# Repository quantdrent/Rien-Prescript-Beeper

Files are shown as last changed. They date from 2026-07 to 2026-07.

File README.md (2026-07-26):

<p align="center"><strong>Rien Index Beeper Device.</strong></p>

<p align="center">
  Rien Prescript Beeper Thumbnail
    <br/>
   
</p>

<p align="center">
The main goal for this project was to make a budget Index Oracle's proxy / Rien device. This runs on Web BLE (so it connects directly to your browser without needing weird setups). This project is under the MIT license so you are free to do anything with it (this includes selling this stuff) but don't try to gatekeep lol. Also, if you decide to make this, feel free to show me! I wanna see it. Hit up @quantdrent on TikTok, Twitter, and Discord.
<br/><br/>
If you want to use the beeper, <a href="https://quantdrent.github.io/Rien-Prescript-Beeper">visit the Web App</a>. or open the html from source code<br/>
<strong>Note: You need to use a browser that supports Web BLE</strong> (Chrome, Edge, Opera, etc).
</p>

## Features
- **Web BLE Integration:** Control the device, sync settings, and beam prescripts right from Chrome/Edge/Opera (no app installs needed).
- **Custom Prescripts:** Write, import, and export your own custom prescripts via the web interface.
- **Stats Tracking:** Physically tap the capacitive touch buttons to **Pass** or **Fail** a prescript, and the device will keep track of your stats.
- **Deep Sleep Mode:** (Recommended Build only) Actually decent battery life for standby.

## Hardware Versions & Required Materials

> There are three different hardware setups in this project:
> * **The nRF52840 (Recommended Build).** It has a TFT color screen, custom fonts, and deep sleep mode. This is the recommended version you see in the GIF.
> * **The ESP32-C3 (Alternative Build).** This uses the exact same TFT color screen as the recommended build, but runs on a much cheaper ESP32-C3 SuperMini. It lacks deep sleep but is a great budget alternative.
> * **The ESP32-C3 (Legacy OLED Build).** An older, archived build that uses a basic blue 1.3" OLED screen. You can find its firmware in `firmware/ESP32/PrescriptBeeper_Legacy_OLED`.
> 
> **DO NOT mix the parts (if you dont know what youre doing).** The firmwares and 3D printed cases are **NOT** interchangeable between the different screens and boards. Make sure you pick the right firmware and 3D model for your parts.

<details>
<summary><strong>Recommended Build (nRF52840)</strong></summary>

This is the recommended version with a tft color screen, custom proportional fonts, and deep sleep support.

> **Note:** Don't forget to solder the boost pads on the SuperMini board if your battery is more than 500mAh.
>
> The TFT `BL` (Backlight) pin MUST be wired to `GND` for the screen to turn on

**Required Parts:**
- SuperMini nRF52840 [[AliExpress](https://www.aliexpress.com/item/1005006019812115.html)]
- 2.25 Inch TFT LCD Module 76x284 ST7789 [[AliExpress](https://www.aliexpress.com/item/1005011855033572.html)]
- 2x Touch capacitive switches TTP-223 [[AliExpress](https://www.aliexpress.com/item/32964219843.html)]
- Any small buttons that can fit inside the case
- Wires (AWG 24 recommended)
- 3.7V Lipo Battery (just make sure it fits in the case)

**Required Arduino Libraries:**
- `Adafruit GFX Library`
- `Adafruit LittleFS`
- `Adafruit ST7735 and ST7789 Library`
**3D Printing (Case):**
- **For the Recommended Build (nRF52840 Supermini):** Use `models/Case.3mf` or `models/Case.stl`
- *(Tinkercad remix link available in `models/tinkercadlink.txt`. I recommend using `.3mf` files. Best results were on a BambuLab A1 with 0.4 nozzle and SUNLU PLA+ 2.0)*

**Wiring Diagram:**
<p align="center">
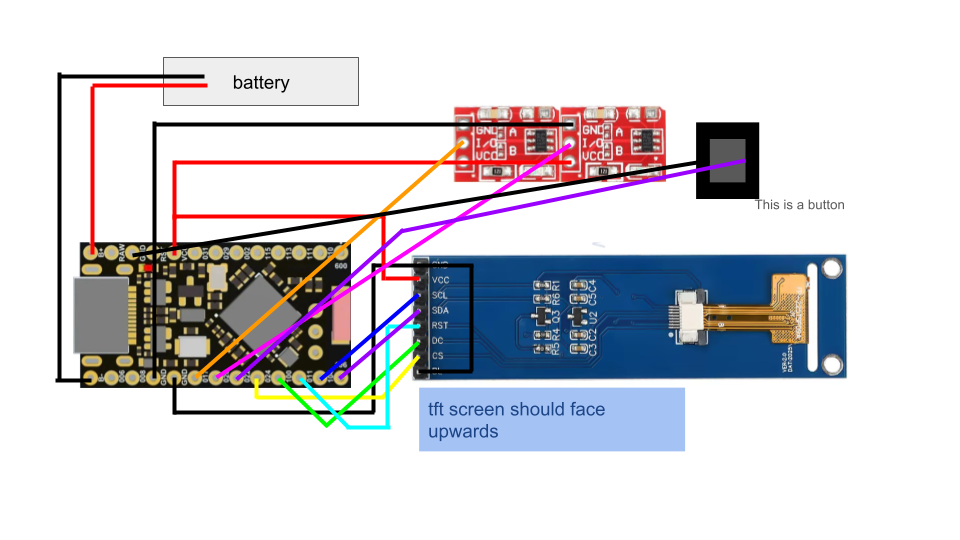
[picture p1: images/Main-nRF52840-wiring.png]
Main nRF52840 Wiring
  
</p>

#### Board Setup (Arduino IDE)
1. Open Arduino v2.x IDE.
2. Go to **File > Preferences**.
3. Click the icon on the right-hand side of “Additional boards manager URLs”.
4. Add the following URL lines into the text box and click OK:
   * **Temporary fix (use this for now):**
     `https://files.seeedstudio.com/arduino/package_seeeduino_boards_index.json`
     `https://raw.githubusercontent.com/pdcook/nRFMicro-Arduino-Core/3dab6477754d9b28053fe36b06c718cde6e93d3f/package_nRFMicro_index.json`
   * *(Note: The official URL without the hash currently has issues, use the temporary fix).*
5. Go to the Boards Manager (**Tools > Board > Boards Manager**).
6. Search for “nrfmicro”.
7. Find the “nRFMicro-like-Boards” by pdcook, and click “Install”.
8. Go to **Tools > Board > nRFMicro-like-Boards > “SuperMini nRF52840”** (Restart Arduino IDE if it is not listed).
9. Plug in your board to a USB port, click the board selector, and choose the relevant port.

#### Updating the Bootloader
The SuperMini nRF52840 boards have nice!nano v2 compatibility, meaning the Adafruit nRF52 Bootloader can be easily updated.

1. Open your file explorer and look for a USB drive related to your board, often called “NICENANO” (if it isn’t visible, quickly ground the RST pin twice to enter bootloader mode).
2. Inside, `INFO_UF2.TXT` is a small text file that states the current bootloader version.
3. You can see the latest bootloader version on the [bootloader github releases page](https://github.com/adafruit/Adafruit_nRF52_Bootloader/releases).
4. **To update via Arduino IDE:**
   * Go to **Tools > Programmer**, and select **“Bootloader DFU for Bluefruit nRF52”**.
   * Go to **Tools > Burn Bootloader**.
   * **Be patient whilst the bootloader is updated. It is critical not to disconnect mid-update, as you could brick the board.**
5. Once updated, recheck the `INFO_UF2.TXT` file to ensure the version has updated (e.g., from 0.6.0 to 0.9.2).
</details>

<details>
<summary><strong>Alternative Build (ESP32-C3 TFT)</strong></summary>

This version is kept here because the ESP32 parts are generally much cheaper and easier to source than the nRF52840, while still allowing you to use the premium TFT color screen.

> **If you are using an ESP32C3** check out [this guide](https://randomnerdtutorials.com/getting-started-esp32-c3-super-mini/) to set up your board in Arduino IDE.
>
> The TFT `BL` (Backlight) pin MUST be wired to `GND` for the screen to turn on

instruction for this version have not been completed. this was a port made by someone else

**Required Parts:**
- ESP32C3 SuperMini (any ESP32 SuperMini should work)
- 2.25 Inch TFT LCD Module 76x284 ST7789 [[AliExpress](https://www.aliexpress.com/item/1005011855033572.html)]
- 2x Touch capacitive switches TTP-223 [[AliExpress](https://www.aliexpress.com/item/32964219843.html)]
- Any small slide switch that fits inside the case [[AliExpress](https://www.aliexpress.com/item/1005011902173007.html)]
- Wires (AWG 26 recommended)

(optional)
- Any small slide switch that fits inside the case [[AliExpress](https://www.aliexpress.com/item/1005011902173007.html)]
- TP4056 Type-C Charger [[AliExpress](https://www.aliexpress.com/item/1005006043031985.html)]
- 3.7V Lipo Battery (just make sure it fits in the case)

**Required Arduino Libraries:**
- `Adafruit GFX Library`
- `Adafruit LittleFS`
- `Adafruit ST7735 and ST7789 Library`

**3D Printing (Case):**
- **For the Alternative Build (ESP32-C3 Supermini):** Use `models/Case.3mf` or `models/Case.stl`
- Best results were on a BambuLab A1 with 0.4 nozzle and SUNLU PLA+ 2.0)*

**Wiring Table:**
| ESP32-C3 SuperMini Pin | Component / Peripheral Pin |
| :--- | :--- |
| **`GPIO 0`** | TFT `MOSI` (or `SDA`) |
| **`GPIO 1`** | TFT `SCLK` (or `SCL`) |
| **`GPIO 2`** | TFT `CS` |
| **`GPIO 3`** | TFT `DC` (or `RS`) |
| **`GPIO 4`** | TFT `RST` |
| **`GPIO 5`** | Pass Button (TTP-223) `I/O` |
| **`GPIO 6`** | Fail Button (TTP-223) `I/O` |
| **`3.3V`** | TFT `VCC`, Buttons `VCC` |
| **`GND`** | TFT `GND`, TFT `BL`, Buttons `GND` |

*(Note: For the charging module, solder it the exact same way as shown in the Legacy version's wiring diagram. The slide switch does not connect to a GPIO pin; wire it inline with the OUT+ of the charging module to act as a physical power switch).*
</details>

<details>
<summary><strong>Legacy Build (ESP32-C3 OLED)</strong></summary>

This is the archived legacy version using a monochrome OLED. You can find its firmware in `firmware/ESP32/PrescriptBeeper_Legacy_OLED`.

**Required Parts:**
- ESP32C3 Super Mini
- 1.3 Inch OLED Screen SH1106 [[AliExpress](https://www.aliexpress.com/item/1005006862867338.html)]
- 2x Touch capacitive switches TTP-223
- Wires (AWG 26 recommended)

(optional)
- Any small slide switch that fits inside the case [[AliExpress](https://www.aliexpress.com/item/1005011902173007.html)]
- TP4056 Type-C Charger [[AliExpress](https://www.aliexpress.com/item/1005006043031985.html)]
- 3.7V Lipo Battery (just make sure it fits in the case)

**Required Arduino Libraries:**
- `Adafruit GFX Library`
- `Adafruit SH110X`

**3D Printing (Case):**
- **For the Legacy Build (ESP32-C3 Supemini):** Use `models/Legacy-Case.3mf` or `models/Legacy-Case.stl`
- I recommend using `.3mf` files. Best results were on a BambuLab A1 with 0.4 nozzle and SUNLU PLA+ 2.0)*

**Wiring Diagram:**
<p align="center">
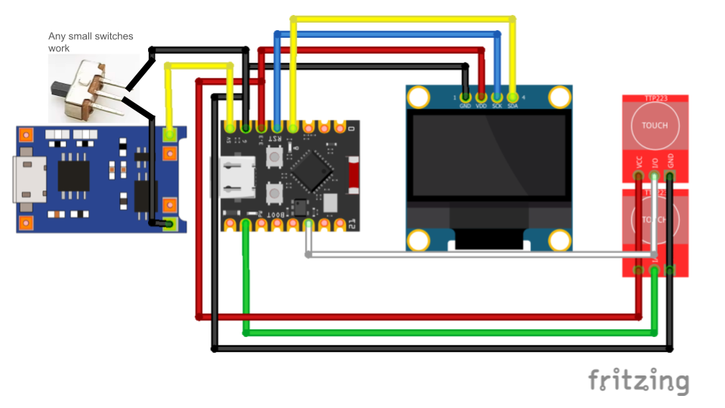
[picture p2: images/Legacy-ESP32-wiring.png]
Legacy ESP32 Wiring
  
</p>

*(Note: The slide switch does not connect to a GPIO pin; wire it inline with the OUT+ of the charging module to act as a physical power switch, as shown in the diagram).*
</details>

## Quickstart

### Instructions

> **Note:** some knowledge of soldering is needed. Don't forget you need a soldering iron, solder, and maybe some flux to connect them all

1. Click the `<> Code` button and download the ZIP, or check releases.
2. Open the `firmware/` folder, select your microcontroller's folder, and open the `.ino` file in the Arduino IDE.
3. Solder everything together based on the pins defined in your firmware's `config.h` file or refer to the hardware sections above for wiring diagrams. 
4. Upload the sketch to your board.
5. Open the [Web App](https://quantdrent.github.io/Rien-Prescript-Beeper) in your browser (or open the local `index.html` file to use offline).
6. Click **Pair Device** and connect to your beeper and your device should work now.
7. Click **Prescripts** at the top middle to add or remove your saved prescripts. You can also export/import them (export first to see the formatting template).
8. Click the giant button on the web app to send a random prescript, or physically tap the capacitive buttons on your device to pull one up.
9. You can factory reset the device by pressing the red button at the bottom right of the settings menu.

## Credits
This project and the Web BLE page were inspired by and forked from Kritzkingvoid's Prescript web project.
https://kritzkingvoid.github.io/Prescripts/

Sounds were taken from Limbus Company / Project Moon.

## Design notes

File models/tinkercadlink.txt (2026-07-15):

this is for the normal case, legacy version is long gone lol

https://www.tinkercad.com/things/3YSkI8xj62Y-rien-index-beeper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

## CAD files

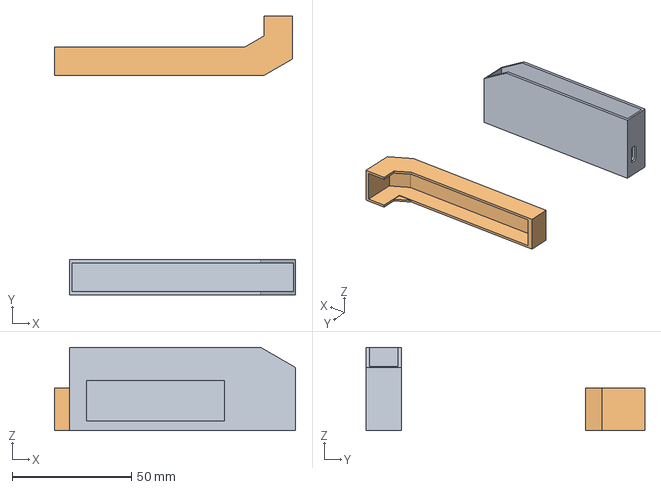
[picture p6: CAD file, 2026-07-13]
models/Case.3mf
101.4 x 117.1 x 35.0 mm
Grand Waasa-Trug(2).stl_5
Grand Waasa-Trug(2).stl_2

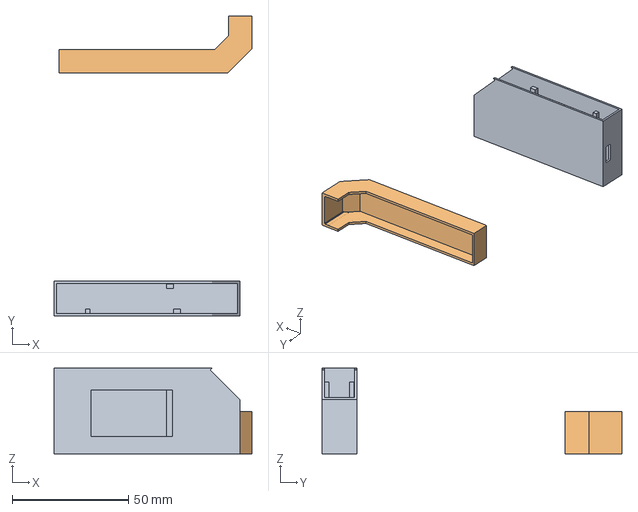
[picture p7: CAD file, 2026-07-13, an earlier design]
models/Legacy-Case.3mf
85.2 x 129.2 x 37.0 mm
larp.stl_2
larp.stl_1

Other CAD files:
models/Case.stl
models/Legacy-Case.stl

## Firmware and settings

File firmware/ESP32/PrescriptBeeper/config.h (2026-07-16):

#ifndef CONFIG_H
#define CONFIG_H

#include <Arduino.h>

extern int textScale;
extern int scrambleDurationFrames;
extern int scrambleDelayMs;
extern int revealDelayMs;
extern int timerPosition;
extern float timerScale;
extern bool bleRequirePin;
extern bool useProportionalFont;

#define TFT_WIDTH 284
#define TFT_HEIGHT 76

#define TFT_MOSI  0
#define TFT_SCLK  1
#define TFT_CS    2
#define TFT_DC    3
#define TFT_RST   4

#define BUTTON_PASS_PIN  5
#define BUTTON_FAIL_PIN  6

#define DEBOUNCE_DELAY  50

#define BLE_CHUNK_SIZE      20
#define BLE_CHUNK_DELAY_MS  10

#define CUSTOMS_FILE    "/customs.txt"
#define STATS_FILE      "/stats.txt"
#define SETTINGS_FILE   "/settings.txt"

#define DEFAULT_TEXT_SCALE          1
#define DEFAULT_SCRAMBLE_FRAMES     20
#define DEFAULT_SCRAMBLE_DELAY      20
#define DEFAULT_REVEAL_DELAY        20

#define COLOR_BG    0x0000
#define DEFAULT_TEXT_COLOR 0xBF5F
extern uint16_t textColor;
extern bool timerFormatLong;

#endif

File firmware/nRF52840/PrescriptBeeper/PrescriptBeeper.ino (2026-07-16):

#include <nrf_wdt.h>
#include "config.h"
#include "display.h"
#include "storage.h"
#include "ble_handler.h"

unsigned long lastDebounceTimePass = 0;
unsigned long lastDebounceTimeFail = 0;
unsigned long lastDebounceTimePower = 0;
int lastPassState = HIGH;
int lastFailState = HIGH;
int lastPowerState = HIGH;
bool passHandled = false;
bool failHandled = false;
unsigned long powerPressedTime = 0;
bool bleRequirePin = false;

void enterSleep() {
  Serial.println("CLEARING DISPLAY");
  isDisplaying = false;
  currentDisplayText = "";
  displayIdle();
  tft.fillScreen(COLOR_BG);

  Serial.println("STOPPING BLE");
  Bluefruit.Advertising.stop();
  if (Bluefruit.connected()) {
    Bluefruit.disconnect(Bluefruit.connHandle());
  }
  delay(200);

  Serial.println("KILLING VCC");
  digitalWrite(EXT_VCC, LOW);
  delay(100);

  Serial.println("WAITING FOR BUTTON RELEASE");
  while(digitalRead(BUTTON_POWER_PIN) == LOW) {
    delay(10);
  }
  delay(300);

  Serial.println("SLEEP STEP 5: CONFIGURING WAKEUP PIN");
  nrf_gpio_cfg_sense_input(g_ADigitalPinMap[BUTTON_POWER_PIN], NRF_GPIO_PIN_PULLUP, NRF_GPIO_PIN_SENSE_LOW);

  Serial.println("ENTERING SYSTEM OFF");
  Serial.flush();
  delay(100);

  sd_power_system_off();
  while(1) {
    __WFE();
  }
}

unsigned long displayStartTime = 0;
unsigned long displayDurationMs = 0;
bool isDisplaying = false;
bool isInfinite = false;
String currentDisplayText = "";
bool pendingDisplayUpdate = false;

void setup() {
  Serial.begin(115200);

  pinMode(BUTTON_PASS_PIN, INPUT_PULLUP);
  pinMode(BUTTON_FAIL_PIN, INPUT_PULLUP);
  pinMode(BUTTON_POWER_PIN, INPUT_PULLUP);

  pinMode(EXT_VCC, OUTPUT);
  digitalWrite(EXT_VCC, HIGH);

  InternalFS.begin();
  readSettings();

  displayInit();
  displayIdle();

  bleInit();
  startAdv();

  NRF_WDT->CONFIG = 0x01;
  NRF_WDT->CRV = 32 * 32768;
  NRF_WDT->RREN = 0x01;
  NRF_WDT->TASKS_START = 1;

  randomSeed(analogRead(A0));

  lastPassState = digitalRead(BUTTON_PASS_PIN);
  lastFailState = digitalRead(BUTTON_FAIL_PIN);
  lastPowerState = digitalRead(BUTTON_POWER_PIN);
  passHandled = true;
  failHandled = true;
  lastDebounceTimePass = millis();
  lastDebounceTimeFail = millis();
  lastDebounceTimePower = millis();
}

void loop() {
  NRF_WDT->RR[0] = WDT_RR_RR_Reload;
  handleButtons();
  handleBLE();
  handleDisplayScramble();
  handleDisplayTimer();
  if (pendingDisplayUpdate) {
    pendingDisplayUpdate = false;
    if (String(pendingDisplayText).startsWith("PIN: ")) {
      showPrescriptOnDisplay(pendingDisplayText, 30000, false, false);
    } else {
      showPrescriptOnDisplay(pendingDisplayText, 2000, false, true);
    }
  }

  static String serialBuffer = "";
  while (Serial.available()) {
    char c = Serial.read();
    if (c == '\n') {
      serialBuffer.trim();
      if (serialBuffer.length() > 0) {
        parseCommand(serialBuffer);
      }
      serialBuffer = "";
    } else {
      serialBuffer += c;
    }
  }

  if (!displayScrambling) {
    flushStatsIfNeeded();
  }

  yield();
}

bool simulatePass = false;
bool simulateFail = false;
bool timerTimeoutFail = false;
bool hasShownPrescript = false;
bool requiresResponse = true;

void showPrescriptOnDisplay(const char* text, unsigned long durationMs, bool infinite, bool respond) {
  currentDisplayText = String(text);
  isDisplaying = true;
  isInfinite = infinite;
  displayDurationMs = durationMs;
  requiresResponse = respond;

  if (currentDisplayText != "CLEAR." && currentDisplayText != "FAILED." && currentDisplayText != "Connected." && currentDisplayText != "Disconnected.") {
    if (!currentDisplayText.startsWith("PIN: ")) {
      addStats("0,0,1");
    }
  }

  beginScramble(text);

  displayStartTime = millis();
  hasShownPrescript = true;
}

void handleDisplayTimer() {
  if (!hasShownPrescript) return;
  if (isDisplaying && !isInfinite && !displayScrambling) {
    unsigned long elapsed = millis() - displayFinishedTime;
    if (elapsed < displayDurationMs) {
      updateTimerDisplay(displayDurationMs - elapsed);
    } else {
      if (requiresResponse && currentDisplayText != "CLEAR." && currentDisplayText != "FAILED." && currentDisplayText != "Connected." && currentDisplayText != "Disconnected." && !currentDisplayText.startsWith("PIN: ")) {
        timerTimeoutFail = true;
      } else {
        isDisplaying = false;
        currentDisplayText = "";
        displayIdle();
      }
    }
  }
}

void handleButtons() {
  int passReading = digitalRead(BUTTON_PASS_PIN);
  if (passReading != lastPassState) {
    lastDebounceTimePass = millis();
    if (passReading == HIGH) passHandled = false;
  }
  bool passTriggered = (!passHandled && passReading == LOW && (millis() - lastDebounceTimePass) > DEBOUNCE_DELAY);

  if (passTriggered || simulatePass) {
    bool fromWeb = simulatePass;
    simulatePass = false;
    if (passTriggered) passHandled = true;

    bool isIdleOrFinished = (!isDisplaying || currentDisplayText == "CLEAR." || currentDisplayText == "FAILED." || currentDisplayText == "Connected." || currentDisplayText == "Disconnected." || !requiresResponse);
    if (isIdleOrFinished && !fromWeb) {
      int idx = -1;
      String line = getRandomPrescript(&idx);
      if (line.length() > 0) {
        int dur = 10;
        bool respond = true;
        String text = "";
        if (parsePrescriptLine(line, dur, respond, text)) {
          showPrescriptOnDisplay(text.c_str(), dur * 1000UL, dur == 0, respond);
          if (bleuart.notifyEnabled() && idx >= 0) {
            String evt = "EVT:PRESCRIPT|IDX:" + String(idx) + "\n";
            sendChunked(evt.c_str(), evt.length());
          }
        }
      } else {
        showPrescriptOnDisplay("NO DATA", 1000, false, false);
      }
    } else {
      if (requiresResponse && currentDisplayText != "CLEAR." && currentDisplayText != "FAILED.") {
        addStats("1,0,0");
        if (bleuart.notifyEnabled() && !fromWeb) bleuart.print("EVT:PASS\n");
        showPrescriptOnDisplay("CLEAR.", 800, false, false);
      }
    }
  }
  lastPassState = passReading;

  int failReading = digitalRead(BUTTON_FAIL_PIN);
  if (failReading != lastFailState) {
    lastDebounceTimeFail = millis();
    if (failReading == HIGH) failHandled = false;
  }
  bool failTriggered = (!failHandled && failReading == LOW && (millis() - lastDebounceTimeFail) > DEBOUNCE_DELAY);

  if (failTriggered || simulateFail || timerTimeoutFail) {
    bool fromWeb = simulateFail;
    simulateFail = false;
    bool wasTimeout = timerTimeoutFail;
    timerTimeoutFail = false;

    if (failTriggered) failHandled = true;

    if (isDisplaying || fromWeb || wasTimeout) {
      if (requiresResponse && currentDisplayText != "CLEAR." && currentDisplayText != "FAILED.") {
        addStats("0,1,0");
        if (bleuart.notifyEnabled() && !fromWeb) bleuart.print("EVT:FAIL\n");
        showPrescriptOnDisplay("FAILED.", 800, false, false);
      } else if (!requiresResponse && wasTimeout) {
        displayIdle();
      }
    }
  }
  lastFailState = failReading;

  int powerReading = digitalRead(BUTTON_POWER_PIN);
  if (powerReading != lastPowerState) {
    lastDebounceTimePower = millis();
  }

  if ((millis() - lastDebounceTimePower) > DEBOUNCE_DELAY) {
    if (powerReading == LOW) {
      if (powerPressedTime == 0) {
        powerPressedTime = millis();
        Serial.println("PWR BTN: PRESSED");
      } else if (millis() - powerPressedTime > 1000) {
        Serial.println("PWR BTN: SLEEP TRIGGERED");
        enterSleep();
      }
    } else {
      if (powerPressedTime != 0) {
        Serial.println("PWR BTN: RELEASED");
      }
      powerPressedTime = 0;
    }
  }
  lastPowerState = powerReading;
}

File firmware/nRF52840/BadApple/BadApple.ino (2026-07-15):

//this is a joke version go open the older folder if you want to get the prescript thing

#include <Arduino.h>
#include <SPI.h>
#include "ST7789_nRF52840.h"
#include "frames.h"

#define TFT_CS      D5
#define TFT_DC      D6
#define TFT_RST     D7
#define TFT_MOSI    D9
#define TFT_SCLK    D8

ST7789_nRF tft = ST7789_nRF(TFT_CS, TFT_DC, TFT_RST);

uint16_t frameBuffer[BAD_APPLE_WIDTH * BAD_APPLE_HEIGHT];
int currentFrame = 0;

void setup() {
  Serial.begin(115200);
  pinMode(EXT_VCC, OUTPUT);
  digitalWrite(EXT_VCC, HIGH);
  delay(100);

  SPI.setPins(-1, TFT_SCLK, TFT_MOSI);
  tft.begin();
  tft.setRotation(1);
  tft.fillScreen(ST7789_BLACK);
}

void loop() {
  if (currentFrame >= BAD_APPLE_FRAMES) {
    currentFrame = 0;
  }

  uint32_t start_idx = bad_apple_frame_offsets[currentFrame];
  uint32_t end_idx = bad_apple_frame_offsets[currentFrame + 1];

  uint16_t currentColor = ST7789_BLACK;
  int pixelIdx = 0;

  for (uint32_t i = start_idx; i < end_idx; i++) {
    uint8_t count = bad_apple_data[i];
    
    for (int p = 0; p < count; p++) {
      if (pixelIdx < (BAD_APPLE_WIDTH * BAD_APPLE_HEIGHT)) {
        frameBuffer[pixelIdx++] = currentColor;
      }
    }
    
    if (count != 255) {
      currentColor = (currentColor == ST7789_BLACK) ? 0xBF5F : ST7789_BLACK;
    }
  }

  int x_offset = (284 - BAD_APPLE_WIDTH) / 2;
  int y_offset = (76 - BAD_APPLE_HEIGHT) / 2;
  tft.drawBuffer(x_offset, y_offset, BAD_APPLE_WIDTH, BAD_APPLE_HEIGHT, frameBuffer);

  currentFrame++;
  
  // aprox 10 fps i think
  delay(100);
}

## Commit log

2026-07-09 small tweaks
    Updated wire type specification and added browser support note.
2026-07-10 added models
    [rienbeeper.3mf, rienbeeper.stl]
2026-07-11 Removed screen test and added temporary sleep funtions
    Guide soon
    [rienbeeper.3mf]
2026-07-11 Bug Fix
    Fixed start up visual 'failed' error
    Fixed Ble send delay
    Added full control for both web and device (Pressing Pass, Fail and next affect web too)
    [PrescriptBeeper.ino, ble_handler.h]
2026-07-11 Revision
    Updated README to clarify device recommendations and BLE usage.
2026-07-11 Bug fix again
    fixed string not syncing
    probably the last update
    [PrescriptBeeper.ino, ble_handler.h, storage.h]
2026-07-11 Timer tweaks
2026-07-12 Hotfix optimization patch
    Removed manufacturer tft library
    Added faster and optimized custom library
    Custom fonts on device that fits web
    Fonts now have mono and proportional variant
    Added resend otp button
    Tweaked default numbers for settings
2026-07-12 esp32 legacy build
    ported old esp32 device to work with the website
2026-07-13 v1.0.0 release
    moved web stuff to folderss, ported everything for the esp32 legacy build, and some text bugfix
    [LegacyESP32Build.3mf, LegacyESP32Build.stl, rienbeeper.3mf]
2026-07-15 Reworked readme and more features for nrf52840 version
    Reworked readme to be easier to understand and navigate aswell as a new recolor text feature
    [Advanced-Case.3mf, Advanced-Case.stl, Legacy-Case.3mf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]
2026-07-15 Add ESP32 TFT support and reorganize builds
    Major hardware update: port ESP32 from OLED to TFT display with custom fonts and color support. Archive legacy OLED build separately. Simplify nRF52840 by using standard Adafruit_ST7789 library inste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
2026-07-15 Consolidate case models and update build docs
    Rename Advanced-Case models to Case (3mf and stl) to reflect unified design usage. Update README to reflect that both Advanced and Standard builds use the same case model. Add context to tinkercadlin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
    [Case.3mf, Case.stl]
2026-07-15 Add visual editor, color tags, timer formats
    Major UI, scrambler and firmware updates:
    - Web UI: visual/raw custom editor, preview, inline colorize, infinite-duration support ("-"), {RAND:min-max} macro, tabs and styling.
    - Scrambler: parse/render color tags and {TIMER} inline countdown; more robust reveal logic.
    - Settings: short/long timer format option synced to device.
    - BLE/Customs: safer chunked/custom sync with queuing and longer pacing; send/receive improvements.
    - Firmware (ESP32 & nRF52840): accept "-" as INF, support timer format flag, inline timer rendering, {RAND} expansion, storage/read/write tweaks, pin change (ESP32 pass/fail), improved custom rules streaming.
    - Added premad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
    [PrescriptBeeper.ino, ble_handler.h, config.h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]
2026-07-16 Bugfix and qol
    - Changed infinite timer display from 'INF' to 'nil' across firmware and web UI
    - Enhanced prescript parsing to handle spaces around delimiters and trim whitespace
    - Added case-insensitive {TIMER} tag detection via IS_TIMER_TAG macro
    - Improved custom prescript importing (append instead of replace)
    - Added 'Disconnected.' status handling to firmware displays
    - Reorganized ESP32 Legacy OLED firmware into subfolder structure
    - Fixed timer display hiding for infinite durations
    - Added timerFormatLong support for long-format time display
    - Enhanced documentation with wiring clarifications and examples
    - Added comprehensive example.txt with prescript formatting guide
    [PrescriptBeeper.ino, ble_handler.h, config.h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]
2026-07-17 Improve BLE thread safety and randomization
    Add critical sections and spinlock protection to BLE buffer operations to prevent race conditions. Mark deviceConnected state variables as volatile. Refactor handleBLE to safely copy and process incoming data under lock. Change ESP32 randomSeed to use esp_random() for better entropy. Add connection state checks in sendChunked and cache invalidation when clearing custom rules.
    [PrescriptBeeper.ino, ble_handler.h]

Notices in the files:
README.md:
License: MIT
